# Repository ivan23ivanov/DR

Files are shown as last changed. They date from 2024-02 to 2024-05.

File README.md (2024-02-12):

# Дипломна работа на Иван Иванов 12 Г клас
 # BASS - Bulgarian Automated Smart Sonar, IoT сонар-асистент на риболовеца
bass1

## Съдържание:

- Електрическа схема
  - Компоненти:
    - Микроконтролер - Seeed Studio XIAO ESP32C3
    - Ултразвуков сензор за измерване на дълбочината на водния стълб - JSN-SR04T
    - Комбиниран сензор за измерване на температурата на въздуха и атмосферното налягане - BME280
    - Изолоран цифров температурен сензор за измерване температурата на водата DS18B20
      
- Печатна платка
  - Използвана CAD с-ма - KiCad
  - За изработената платка:
    - Два активни слоя
    - Едностранно разположение на компонентите
    - Ширини на пистите - 0.5 мм (сигнални), 1 мм (захранващи)
      
- Управляващ софтуер
  - Среда за разработка - Visual Studio Code
  - Extention - PlatformIO
  - Взимане на входна информация от сензорите и изчисления
  - Изпращане на информацията към мобилното приложение (за Android OS)
  
- Приложен софтуер
  - Android приложение, използващо Flutter framework-а за Android Studio
  - Приложението съдържа:
   - Екран за сканиране за различни BLE устройства
   - Режим "Сурови данни"
   - Режим "Асистент"
   
- Документация
  - Съдържание:
    - Увод
    - Първа глава - Проучване на съществуващи проекти
    - Втора глава - Основни изисквания и блокови схеми
    - Трета глава - Проектиране на принципна електрическа
    - Четвърта глава - Проектиране на печатна платка
    - Пета глава -  Управляващ и приложен софтуер
    - Шеста глава - Практически резултати
    - Заключение

Файловете на печатната платка, електрическата схема, документацията и софтуера могат да бъдат намерени по-горе в repository-то.

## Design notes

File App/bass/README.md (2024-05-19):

# BASS

A Flutter project.

## Objectives

This project is made specifically to create an application that interacts directly with the Bulgarian Automated Smart Sonar Device, Made by Ivan Ivanov.

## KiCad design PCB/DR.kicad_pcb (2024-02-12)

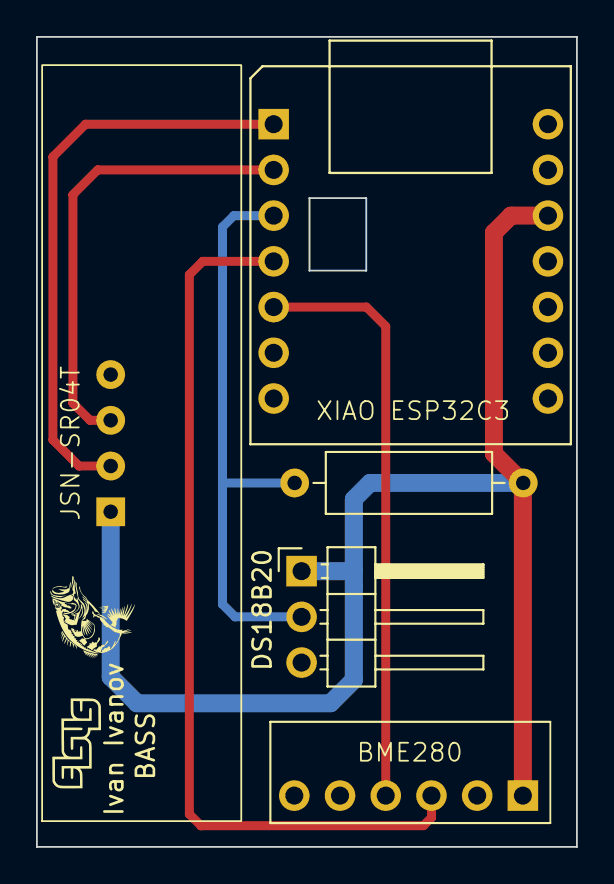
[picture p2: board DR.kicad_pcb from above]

Board: 2 copper layers, 30.0 x 45.0 mm, 5 parts (0 on the bottom side), 7 nets.

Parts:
R1: 4.7k; R_Axial_DIN0309_L9.0mm_D3.2mm_P12.70mm_Horizontal
U1: XIAO ESP32C3
U2: JSN-SR04T
U3: BME280
U4: 3pin conn

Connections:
+3.3V: R1.2, U1.12 (3V3), U2.1 (VCC), U3.1 (VCC), U4.1 (VDD)
DQ: R1.1, U1.3 (D2), U4.2 (DATA)
Echo: U1.2 (D1), U2.3 (Echo)
GNDD: U1.13 (GND), U2.4 (GND), U3.2 (GND), U4.3 (GND)
SCL: U1.4 (D3), U3.3 (SCL)
SDA: U1.5 (D4), U3.4 (SDA)
Trig: U1.1 (D0), U2.2 (Trig)

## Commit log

2024-02-12 Create Sensors test
    Example code for all sensors
2024-02-12 Create Combined sensors test
2024-02-12 Add files via upload
    KiCad files uploaded just in case ;)
    [DR.kicad_pcb, DR.kicad_sch]
2024-02-13 Create Updated pins on sensor test
